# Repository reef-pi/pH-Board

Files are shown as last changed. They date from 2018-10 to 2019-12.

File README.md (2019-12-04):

# reef-pi pH / ORP board

This repository conatins the design files for a standalone pH or ORP printed circuit board for the reef-pi project. Although reef-pi uses Raspberry Pi, this board can be used with arduino as well without any circuit changes.

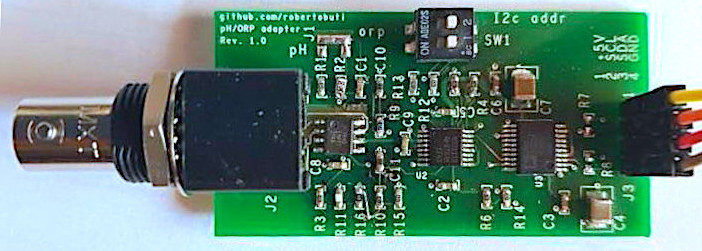
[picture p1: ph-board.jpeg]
reef-pi pH board


This board provieds features to read typical pH or ORP probes using signal amplifier, an analog to digital converter and an optoisolator circuit. This board provides the probe values via an I2C addressable bus interface.
Schematic & PCB are created with Orcad 16, but pdf & gerber files are available if you don't have license for Orcad.

An optocoupled system is not mandatory in an Aquarium, but too often there are splashes & leaks that can cause problems on measurements.  An optocoupled interface solves these problems.
A solder dip switch is provided on the PCB to select the mode (gain) for pH probe or ORP probe.  There is also a 2 way dip switch that offers 4 different I2C addresses, so up to 4 probes can theoretically be connected on the same I2C bus.
Assembly of this circuit requires a bit of experience on SMT component soldering; personally I soldered them by hand without problem.  I will try to give some step by step suggestion on how to complete the soldering. The PCB can be ordered on-line by a large number of manufacturers, or shared from another user.

## Assembly instruction

Passive components are style 0603,small but not smallest, in any case to solder the componenents are necessary SMT welder, tin solder for SMT, SMT tweezers and most important a big lens or a binocular stereoscope, if you don't have similar tool i suggest find some one have it, obviously is required also a confidence with the process.
When soldering process is finished be sure to remove all short circuit and excess of tin, using a copper braid it's good method.
Be sure to clean accuratley the board from flux, specially around U1 & J2, it's special and critical opamp, no flux must be on this ic pins, or you will have problem with pH probe.
J1 must be soldered closign the circuit on pH poistion or ORP position, depend from adapter usage.

Address, basically the board has as address 0x40, up to 4 adapter can be used on same I2c bus, dip switch SW1 need to be set in according with software control system.

Address table, SW1:
```
Slide 1	Slide 2	Address
off	    off	    0x40
on	    off	    0x41
off	    on	    0x42
on	    on	    0x43
```

## Test setup

Connect the board to RPI3, gnd (pin 39) +5V (pin 2) SDA1 (pin3) SCL1 (pin 5), be sure the address is 0x40 (SW1 off),be sure the I2C is enabled on Pi3, run i2cdetect (i2cdetect -y 1), the program must find the device at address 0x40, if not check the solder / connections. For a how to i suggest search with google "pi3 i2cdetect" or something like that, you find a lot of instructions.
Note : if you need to connect more then one adapter all the other will be in parallel, signal by signal, but remember to change the address of each one.

connections picture

When you are sure the I2C channel is working run the program provided for test named "sample". 
The program read the AD converter very quicky, connect the pH probe and place it in buffer solution, like pH4 or pH 10, correct value will be around 20.000 digit at pH 4 and -20.000 at pH 10.
If you read 32768 means out of range, something of wrong happen on analog part.

## Pseudocode for reading probe value

- Base address 0x40
- Init sequence 
```
 write 0x40,0x06  //SW reset 
 write 0x40,0x40,0x06;  //set config reister continuos conversion, 90SPS
 write 0x40,0x08;   // start conversione
```
- Loop to read value periodically:
```
 write 0x40,0x10
 read  // two bytes
````

## LICENSE

CERN Open Hardware Licence v1.2 

## Author

- Roberto Buti

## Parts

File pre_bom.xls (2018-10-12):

ORP-pH | adapter |  | Revised: | Monday, | September | 3 | 2018
PREAMPLIFICATORE | PH | REDOX |  |  |  |  |  |  |  | Revision: | 0
Roberto | Buti
Bill | Of | Materials |  |  |  |  |  | September | 4,2018 |  |  | 13:55:25 | Page1
Item | Quantity | Reference | Part | package | Digikey | P/N
______________________________________________
1 | 1 | C1 | 1nF | 603
2 | 6 | C2,C3,C5,C6,C8,C9 | 100nF | 603
3 | 2 | C4,C7 | 10uF | 1210
4 | 2 | C10,C11 | 1uF | 603
5 | 1 | J1 | JUMPER | 3SMT_NO | nn
6 | 1 | J2 | BNC | Molex | 731375003
7 | 1 | J3 | HEADER | 4 | 100mls | pin | strip
8 | 1 | R1 | 1M | 1% | 603
9 | 1 | R2 | 200K | 1% | 603
10 | 9 | R3,R4,R5,R9,R10, | 10K | 603
 |  | R12,R13,R14,R15
11 | 1 | R6 | 30K | 603
12 | 1 | R11 | 100K | 1% | 603
13 | 1 | R16 | 51K | 1% | 603
14 | 1 | SW1 | SW | DIP-2/SM | SMT | 100mls
15 | 1 | U1 | LMP7721MA | soic8
16 | 1 | U2 | ADS1119IPW | tssop16
17 | 1 | U3 | ADM3260ARSZ | ssop20

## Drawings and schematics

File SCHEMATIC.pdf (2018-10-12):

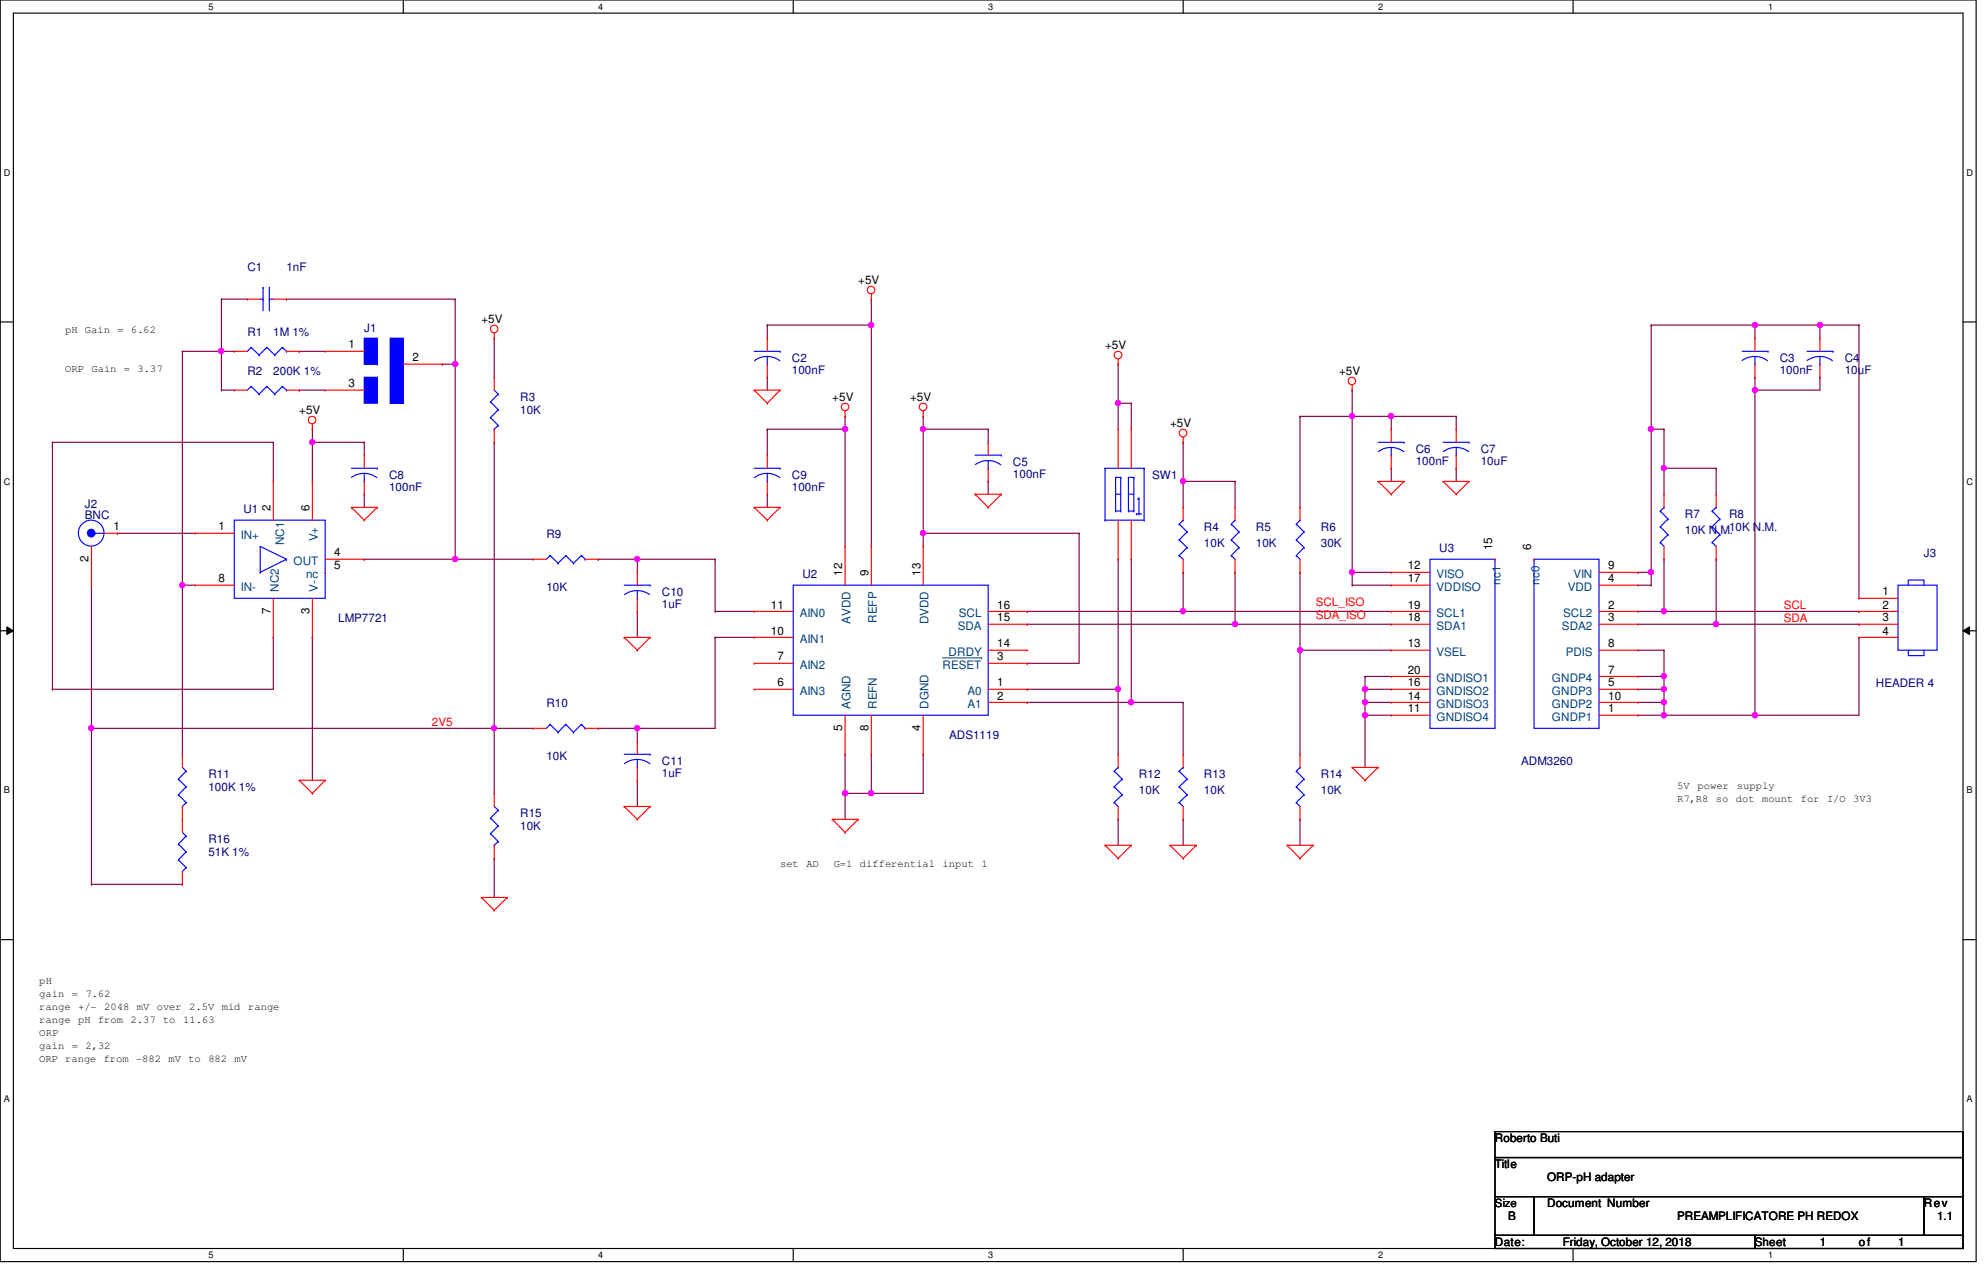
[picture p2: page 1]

5V power supply
R7,R8 so dot mount for I/O 3V3

gain = 7.62
range +/- 2048 mV over 2.5V mid range
range pH from 2.37 to 11.63
ORP
gain = 2,32
ORP range from -882 mV to 882 mV

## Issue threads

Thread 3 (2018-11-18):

Add holes for mounting the board

ranjib, 2018-11-18:
We need at least four mounting holes to mount the board in housing. preferably m2.5/m3 standoffs.

Closed 2020-09-02.

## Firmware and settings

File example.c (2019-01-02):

#include <stdio.h>
#include <unistd.h>
#include <fcntl.h> 			// open
#include <inttypes.h>		 // uint8_t, etc
#include <linux/i2c-dev.h> // I2C bus definitions
#include <sys/ioctl.h>


int main() {
	
  int ADS_address = 0x40;	// base address of our device on the I2C bus
  int I2CFile;
  	
  uint8_t buffer[2];		// 2 byte buffer to store the data read from the I2C device

  int16_t val;				// Stores the 16 bit value of our ADC conversion
  
  I2CFile = open("/dev/i2c-1", O_RDWR);		// Open the I2C device
  
  ioctl(I2CFile, I2C_SLAVE, ADS_address);   // Specify the address of the I2C Slave to communicate with

  buffer[0] = 0x06;  //reset 
  write(I2CFile, buffer, 1);	


  buffer[0] = 0x40;
  buffer[1] = 0x06;				//continuos conversion, 90SPS
//  buffer[1] = 0x00;				//csingle shot conversion, 20SPS 
  write(I2CFile, buffer, 2);	// this set config register
  
  
  
  buffer[0] = 0x20;  //read config only for debug
  write(I2CFile, buffer, 1);	  
  read(I2CFile, buffer, 1);	
  printf("config value %x \n", buffer[0]);
  

  
	buffer[0] = 0x08;
	write(I2CFile, buffer, 1);	  // start conversion

// tentative for single shot conversion mode
	buffer[0] = 0x21;  
	write(I2CFile, buffer, 1);	  // read status register
	
 
// Wait for the conversion to complete, this requires bit 7 to change from 0->1
//  while ((buffer[0] & 0x80) == 0)	// readBuf[0] contains 8 MSBs of config register, AND with 10000000 to select bit 7
//  {
//	  buffer[0] = 0x21;  	// not sure if need all the time
//	  write(I2CFile, buffer, 1);	  // read status register
//	  read(I2CFile, buffer, 1);	// Read the status register into readBuf
//	  printf("status %x \r", buffer[0]);
//  }

while (1)
  {
  buffer[0] = 0x10;
  write(I2CFile, buffer, 1);	// command to read value
  
  read(I2CFile, buffer, 2);		// Read the contents of the conversion register into readBuf

  val = buffer[0] << 8 | buffer[1];	// Combine the two bytes of readBuf into a single 16 bit result 
  
  printf("AD Reading %d \r", val);	// Print the result to terminal
}		
  close(I2CFile);
  
  return 0;

}

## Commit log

2018-09-18 Add files via upload
    Added pcb files, source, gerber, pdf gerber.
    [orp_ph.brd]
2018-10-12 updated tested scheamatic version 1.1
    [PREAMPLI_REV1_1.DSN, pre_bom.xls]
2018-10-14 updated pcb rev 1
    [orp_ph_rev1.brd]
2018-12-30 rename schematic image
2018-12-30 remove pdf rendering of the board, it can always be generated from the project file. Schematic is included for ease
